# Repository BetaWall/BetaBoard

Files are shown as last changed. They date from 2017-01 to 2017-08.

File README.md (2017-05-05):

*Chat to the devs on [Telegram](https://t.me/joinchat/AAAAAAxiRIuuax58XAVMrQ).*

BetaBoard

A multiplexed APA102 LED driver board for the BetaWall system.

## Features

- Input runs through a single RJ45 connector via RS-485 protocol.
- Outputs SPI to APA102 LEDs.
- Supports up to 32 strips of 256 LEDs.
- Supports daisychaining of up to 128 BetaBoards to drive a total of over 1 Million LEDs.

## Block Diagram
Block Diagram

AGPLv3

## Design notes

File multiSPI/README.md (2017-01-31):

# multiSPI

Scripts that talk SPI to APA102 LEDs using the multiplexing technology on the BetaBoard hardware. 

These are currently written in Python, however the final project will have the SPI multiplexing handled by hardware and this software will only be used for image proccessing and serial output to the BetaBoard.

These are tested and working on a Raspberry Pi 2 running Ubuntu Server.

## Dependancies

Uses WiringPi for the multiplexing, needs to be run on a linux machine with SPI hardware at `/dev/spidev0.0`. This is hardcoded and can be changed by editing the source.

Otherwise the software just uses your device as a file so no SPI libraries are required.

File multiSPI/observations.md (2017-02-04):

# Observations though Practical Testing

Testing shows that outputting data at the default Pi SPI datarate will support 18x21 at 20fps.

By the nature of the APA102 it is faster to wire in less lines of more LEDs.

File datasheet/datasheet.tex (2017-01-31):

\documentclass[a4paper]{article}

\title{BetaBoard Datasheet \texttt{Preliminary}}
\author{Harry Beadle, George Brown}

\usepackage{graphicx}
\usepackage{float}
\usepackage[margin=1in]{geometry}

\begin{document}

\maketitle

\section*{18 Strip APA102 Multiplexer and Driver over RS485}

\section{Features}
\begin{itemize}
\item Drives up to 18 Strips of 255 LEDs, totaling up to 4590 APA102 devices.
\item Takes input using the RS485 protocol.
\item Supports up to 40A continuous current driving the LEDS, with the ability to support much higher output currents with auxiliary power supplies.
\end{itemize}

\begin{figure}[H]
\centering

\caption{Block Diagram}
\end{figure}

\subsection{Protocols}\label{protocols}

\subsubsection{RS485 Data Packet Format}\label{rs485-data-packet-format}

The RS485 Packet is sent from the compute platform to the BetaBoard. It
contains the address of the board, the strip for which the LED data is
for and the LED data.

\begin{center}
\begin{verbatim}
ID[8] STRIP[8] DATA_LENGTH[8] LED1[24] LED2[24] ... LEDN[24]
\end{verbatim}

\begin{table}[H]
\begin{tabular}{lll}
Tag & Bits & Description \\
\hline
\texttt{ID} & 8 & Board ID  \\
\texttt{STRIP} & 8 & Strip Address  \\
\texttt{DATA-LENGTH} & 8 & Number of LEDs to be set from packet \\
\texttt{LED}$n$ & 24 & Three bytes for each color of each LED, in the format \texttt{BGR}
\end{tabular}
\end{table}
\end{center}

As an example setting 1 LED in strip \texttt{0x00} on board ID \texttt{0x00} to \texttt{0xFFFFFF}:

\begin{verbatim}
ID------- STRIP---- DATA_LEN- LED1-------------------------
0000 0000 0000 0000 0000 0001 1111 1111 1111 1111 1111 1111
\end{verbatim}

\end{document}

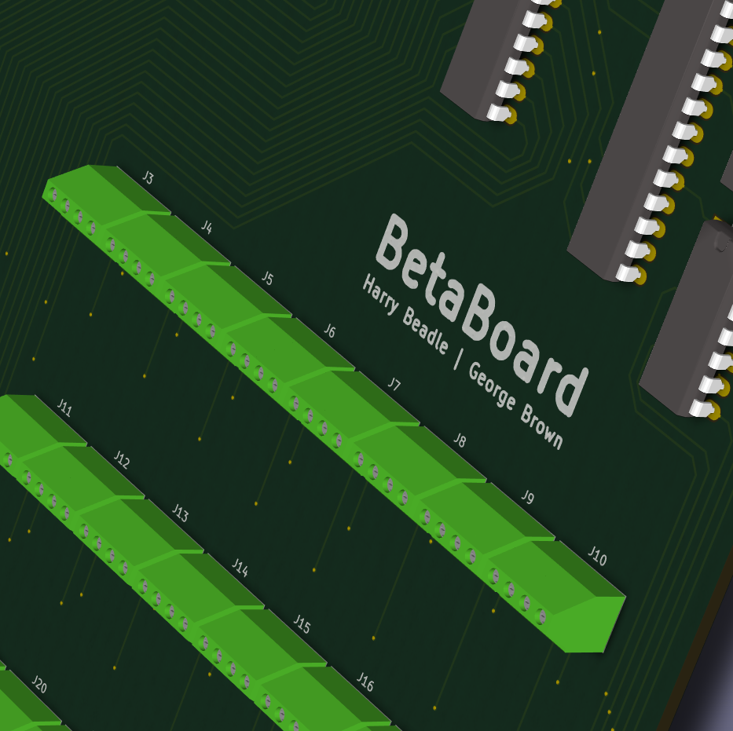
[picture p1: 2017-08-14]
KiCad/3d-render.png

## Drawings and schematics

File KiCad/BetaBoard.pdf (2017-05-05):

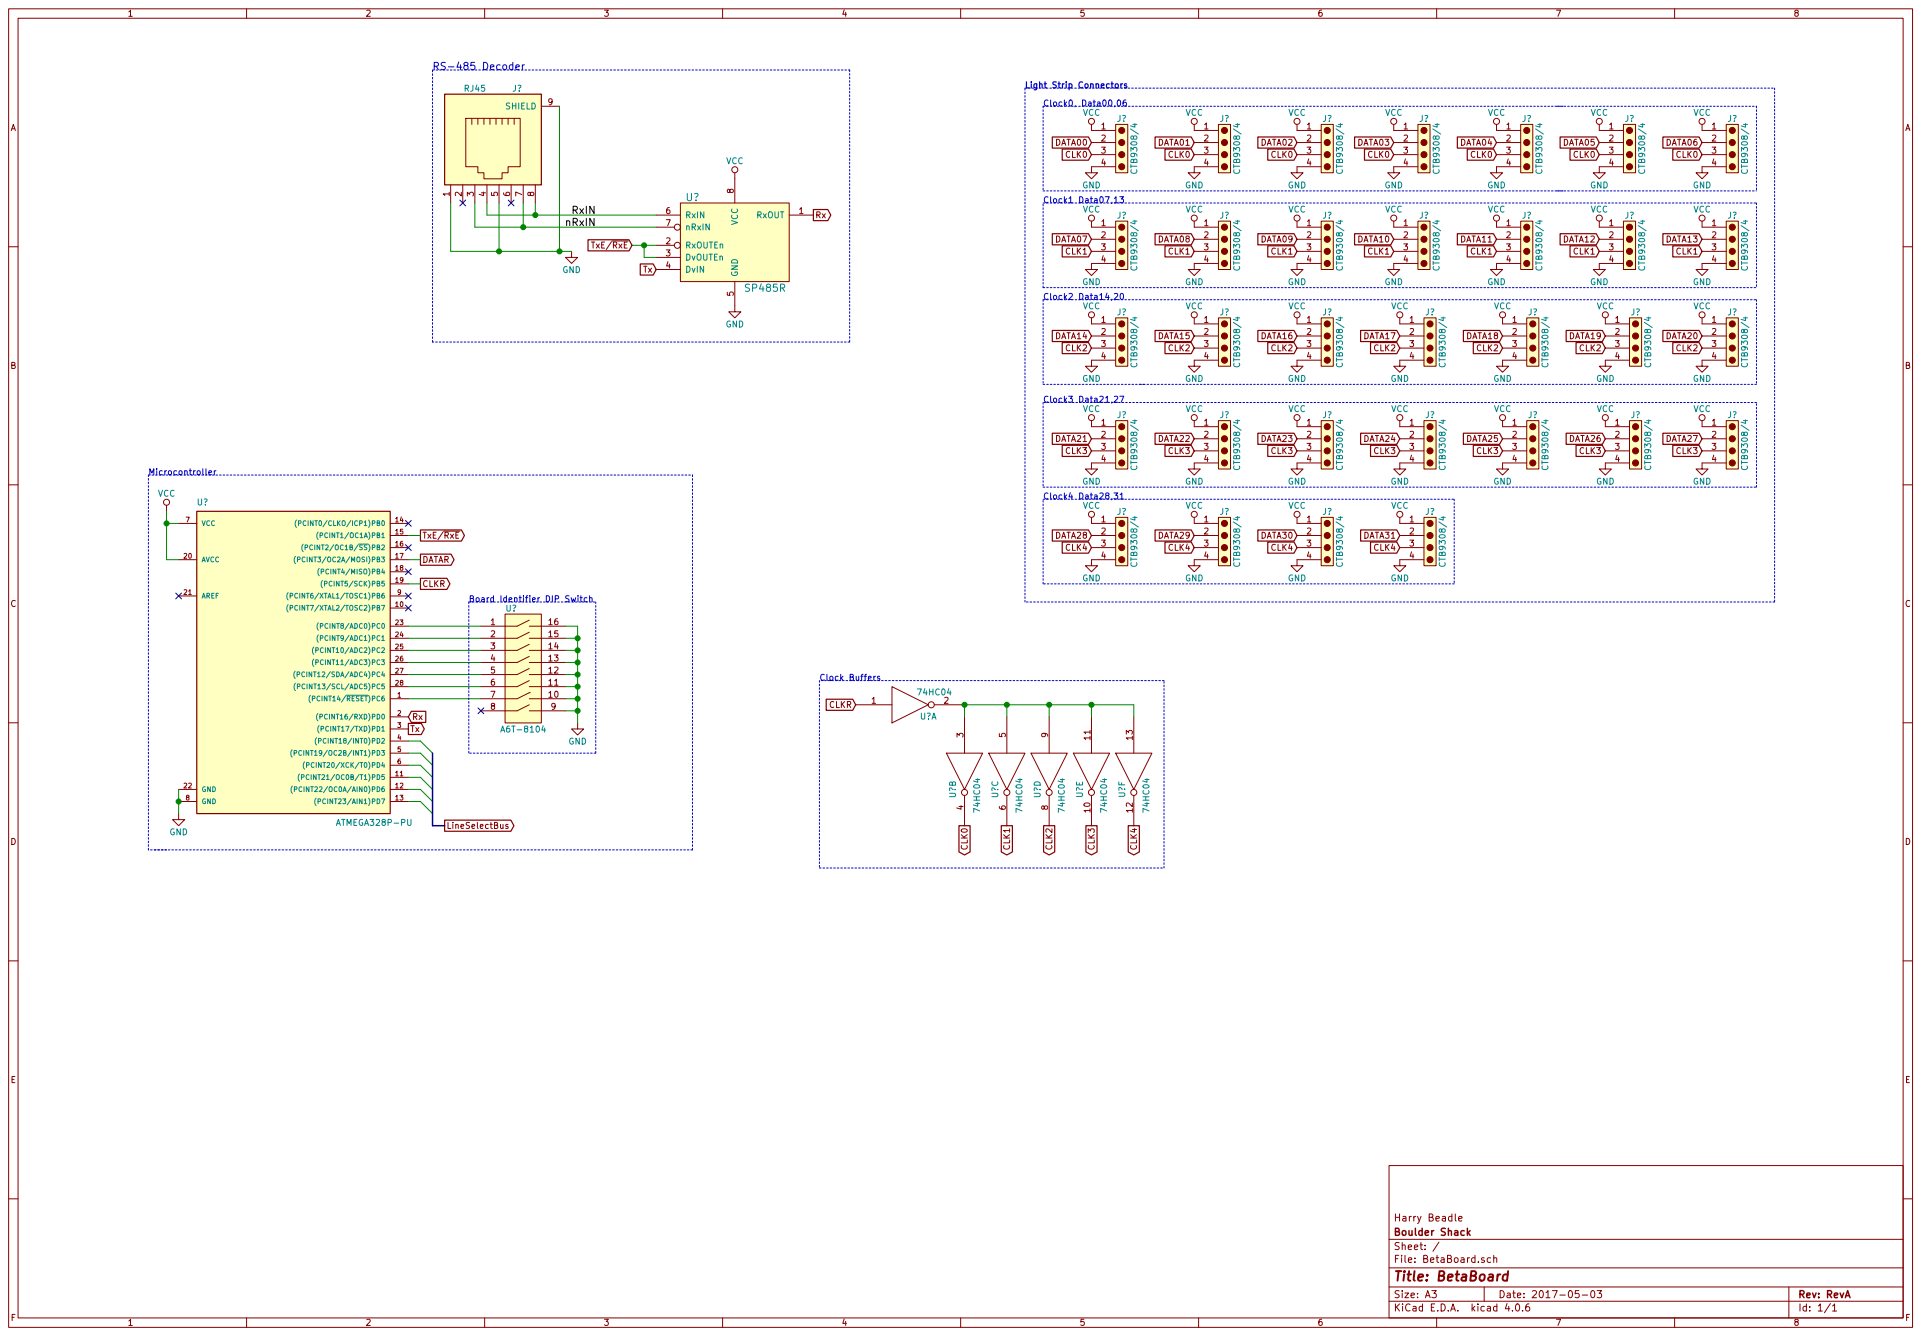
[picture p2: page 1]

VCC GND
Tx TxE/RxE Rx Tx TxE/RxE CLKR

File: BetaBoard.sch Sheet: / Boulder Shack Harry Beadle

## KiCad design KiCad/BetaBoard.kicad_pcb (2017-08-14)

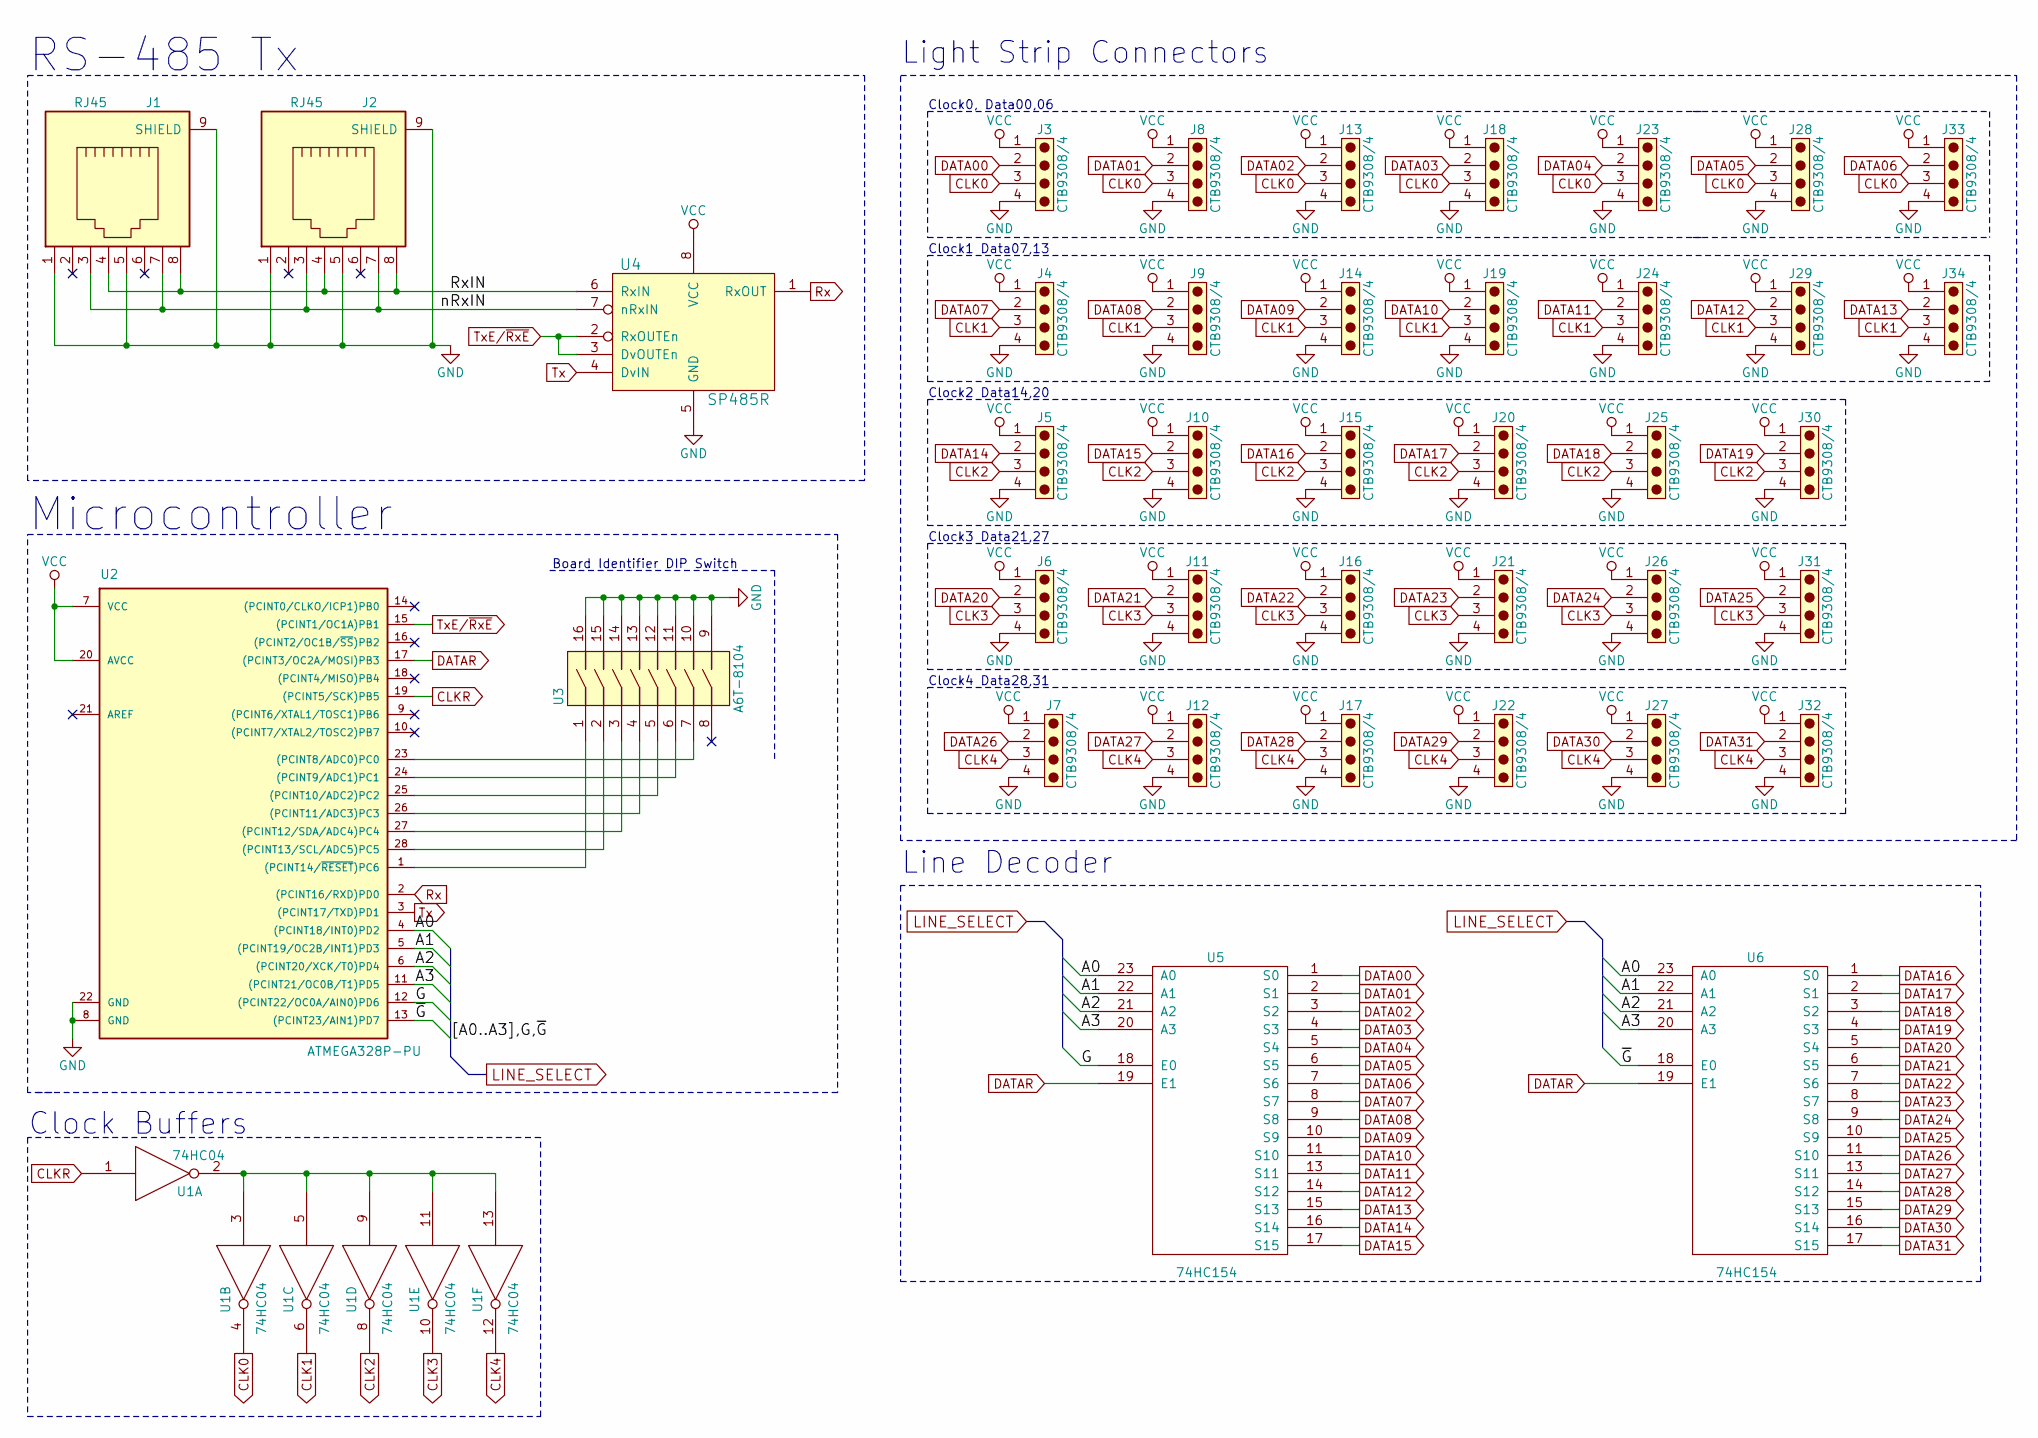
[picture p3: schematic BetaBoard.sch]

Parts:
J1, J2: RJ45; RJ45_TRANSFO_ver2
J3, J4, J5, J6, J7, J8, J9, J10, J11, J12, J13, J14, J15, J16, J17, J18, J19, J20, J21, J22, J23, J24, J25, J26, J27, J28, J29, J30, J31, J32, J33, J34: CTB9308/4; TerminalBlock_Pheonix_MPT-2.54mm_4pol
U1: 74HC04; DIP-14_W7.62mm_Socket_LongPads
U2: ATMEGA328P-PU; DIP-28_W7.62mm_Socket_LongPads
U3: A6T-8104; DIP-16_W7.62mm_Socket_LongPads
U4: SP485R; DIP-8_W7.62mm_Socket_LongPads
U5, U6: 74HC154; DIP-24_W7.62mm_Socket_LongPads

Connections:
/A0: U2.4 ((PCINT18/INT0)PD2), U5.23 (A0), U6.23 (A0)
/A1: U2.5 ((PCINT19/OC2B/INT1)PD3), U5.22 (A1), U6.22 (A1)
/A2: U2.6 ((PCINT20/XCK/T0)PD4), U5.21 (A2), U6.21 (A2)
/A3: U2.11 ((PCINT21/OC0B/T1)PD5), U5.20 (A3), U6.20 (A3)
/G: U2.12 ((PCINT22/OC0A/AIN0)PD6), U5.18 (E0)
/RxIN: J1.4, J1.8, J2.4, J2.8, U4.6 (RxIN)
/nRxIN: J1.3, J1.7, J2.3, J2.7, U4.7 (nRxIN)
/~G: U2.13 ((PCINT23/AIN1)PD7), U6.18 (E0)
CLK0: J3.3, J8.3, J13.3, J18.3, J23.3, J28.3, J33.3, U1.4
CLK1: J4.3, J9.3, J14.3, J19.3, J24.3, J29.3, J34.3, U1.6
CLK2: J5.3, J10.3, J15.3, J20.3, J25.3, J30.3, U1.8
CLK3: J6.3, J11.3, J16.3, J21.3, J26.3, J31.3, U1.10
CLK4: J7.3, J12.3, J17.3, J22.3, J27.3, J32.3, U1.12
CLKR: U1.1, U2.19 ((PCINT5/SCK)PB5)
DATA00: J3.2, U5.1 (S0)
DATA01: J8.2, U5.2 (S1)
DATA02: J13.2, U5.3 (S2)
DATA03: J18.2, U5.4 (S3)
DATA04: J23.2, U5.5 (S4)
DATA05: J28.2, U5.6 (S5)
DATA06: J33.2, U5.7 (S6)
DATA07: J4.2, U5.8 (S7)
DATA08: J9.2, U5.9 (S8)
DATA09: J14.2, U5.10 (S9)
DATA10: J19.2, U5.11 (S10)
DATA11: J24.2, U5.13 (S11)
DATA12: J29.2, U5.14 (S12)
DATA13: J34.2, U5.15 (S13)
DATA14: J5.2, U5.16 (S14)
DATA15: J10.2, U5.17 (S15)
DATA16: J15.2, U6.1 (S0)
DATA17: J20.2, U6.2 (S1)
DATA18: J25.2, U6.3 (S2)
DATA19: J30.2, U6.4 (S3)
DATA20: J6.2, U6.5 (S4)
DATA21: J11.2, U6.6 (S5)
DATA22: J16.2, U6.7 (S6)
DATA23: J21.2, U6.8 (S7)
DATA24: J26.2, U6.9 (S8)
DATA25: J31.2, U6.10 (S9)
DATA26: J7.2, U6.11 (S10)
DATA27: J12.2, U6.13 (S11)
DATA28: J17.2, U6.14 (S12)
DATA29: J22.2, U6.15 (S13)
DATA30: J27.2, U6.16 (S14)
DATA31: J32.2, U6.17 (S15)
DATAR: U2.17 ((PCINT3/OC2A/MOSI)PB3), U5.19 (E1), U6.19 (E1)
GND: J1.1, J1.5, J1.9 (SHIELD), J2.1, J2.5, J2.9 (SHIELD), J3.4, J4.4, J5.4, J6.4, J7.4, J8.4, J9.4, J10.4, J11.4, J12.4, J13.4, J14.4, J15.4, J16.4, J17.4, J18.4, J19.4, J20.4, J21.4, J22.4, J23.4, J24.4, J25.4, J26.4, J27.4, J28.4, J29.4, J30.4, J31.4, J32.4, J33.4, J34.4, U1.7 (GND), U2.8 (GND), U2.22 (GND), U3.9, U3.10, U3.11, U3.12, U3.13, U3.14, U3.15, U3.16, U4.5 (GND), U5.12 (GND), U6.12 (GND)
unnamed: U1.2, U1.3, U1.5, U1.9, U1.11, U1.13
unnamed: U2.1 ((PCINT14/~RESET~)PC6), U3.1
unnamed: U2.23 ((PCINT8/ADC0)PC0), U3.7
unnamed: U2.24 ((PCINT9/ADC1)PC1), U3.6
unnamed: U2.25 ((PCINT10/ADC2)PC2), U3.5
unnamed: U2.26 ((PCINT11/ADC3)PC3), U3.4
unnamed: U2.27 ((PCINT12/SDA/ADC4)PC4), U3.3
unnamed: U2.28 ((PCINT13/SCL/ADC5)PC5), U3.2
Rx: U2.2 ((PCINT16/RXD)PD0), U4.1 (RxOUT)
Tx: U2.3 ((PCINT17/TXD)PD1), U4.4 (DvIN)
TxE/~RxE: U2.15 ((PCINT1/OC1A)PB1), U4.2 (RxOUTEn), U4.3 (DvOUTEn)
VCC: J3.1, J4.1, J5.1, J6.1, J7.1, J8.1, J9.1, J10.1, J11.1, J12.1, J13.1, J14.1, J15.1, J16.1, J17.1, J18.1, J19.1, J20.1, J21.1, J22.1, J23.1, J24.1, J25.1, J26.1, J27.1, J28.1, J29.1, J30.1, J31.1, J32.1, J33.1, J34.1, U1.14 (VCC), U2.7 (VCC), U2.20 (AVCC), U4.8 (VCC), U5.24 (VCC)

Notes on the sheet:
RS-485 Tx
Board Identifier DIP Switch
Microcontroller
Clock0, Data00,06
Clock1 Data07,13
Clock2 Data14,20
Clock3 Data21,27
Clock4 Data28,31
Clock Buffers
Light Strip Connectors
Line Decoder

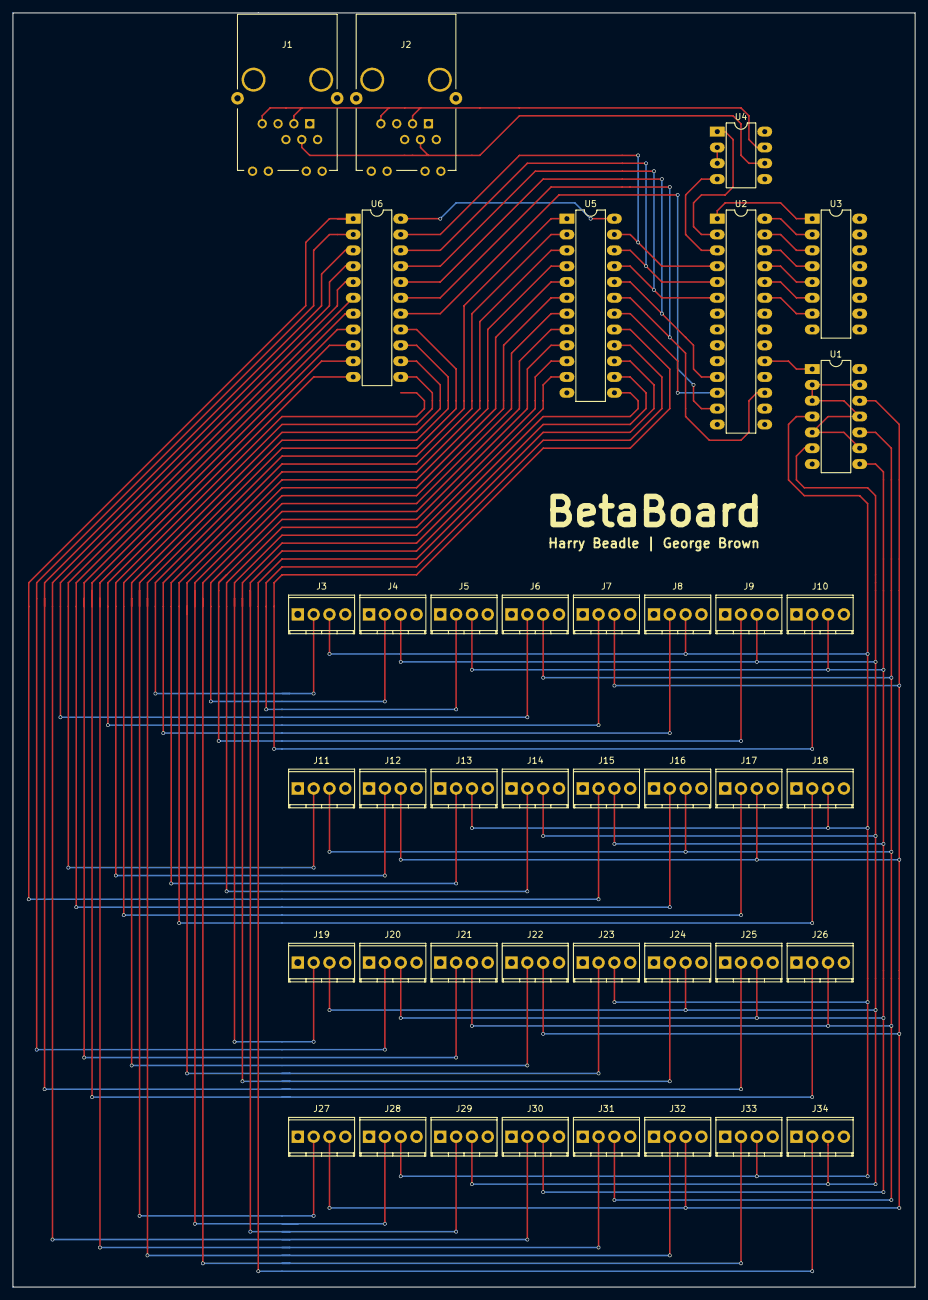
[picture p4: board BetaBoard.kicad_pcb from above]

Board: 2 copper layers, 144.8 x 204.5 mm, 40 parts (0 on the bottom side), 60 nets.

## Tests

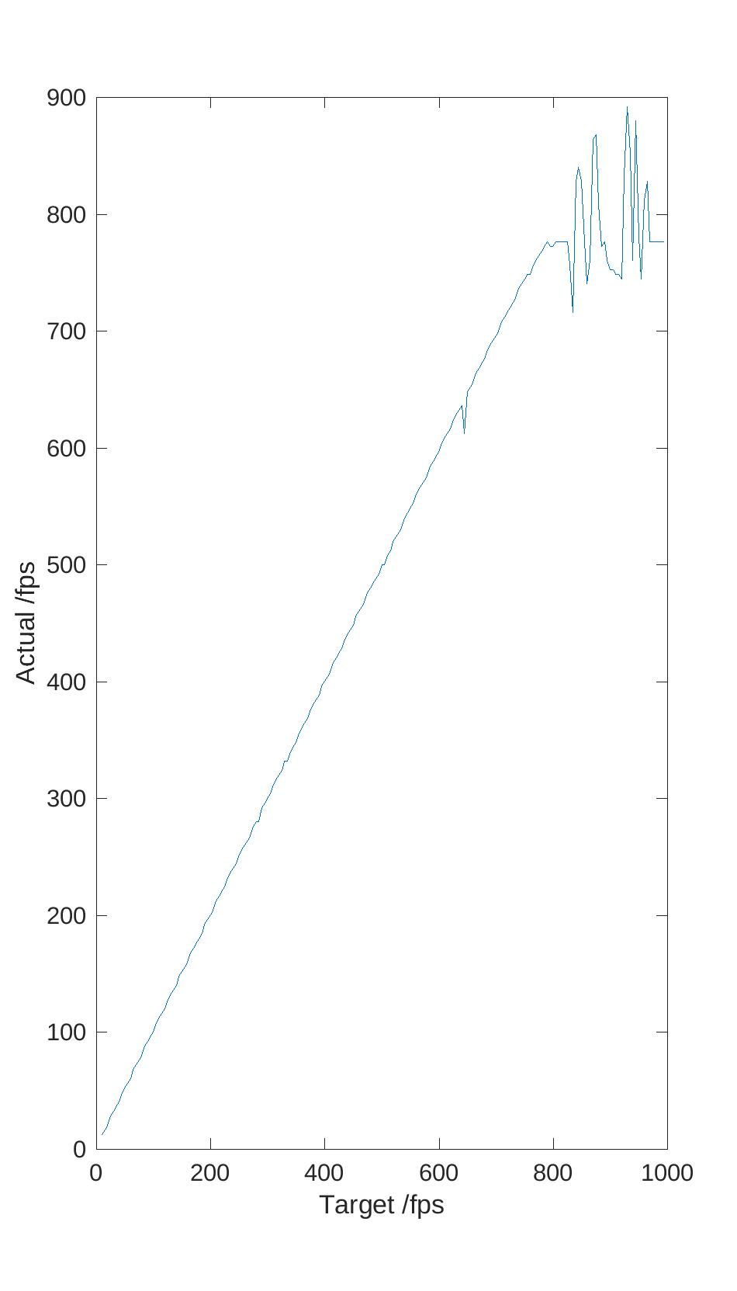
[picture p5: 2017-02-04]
multiSPI/test-suite/frametest.jpg

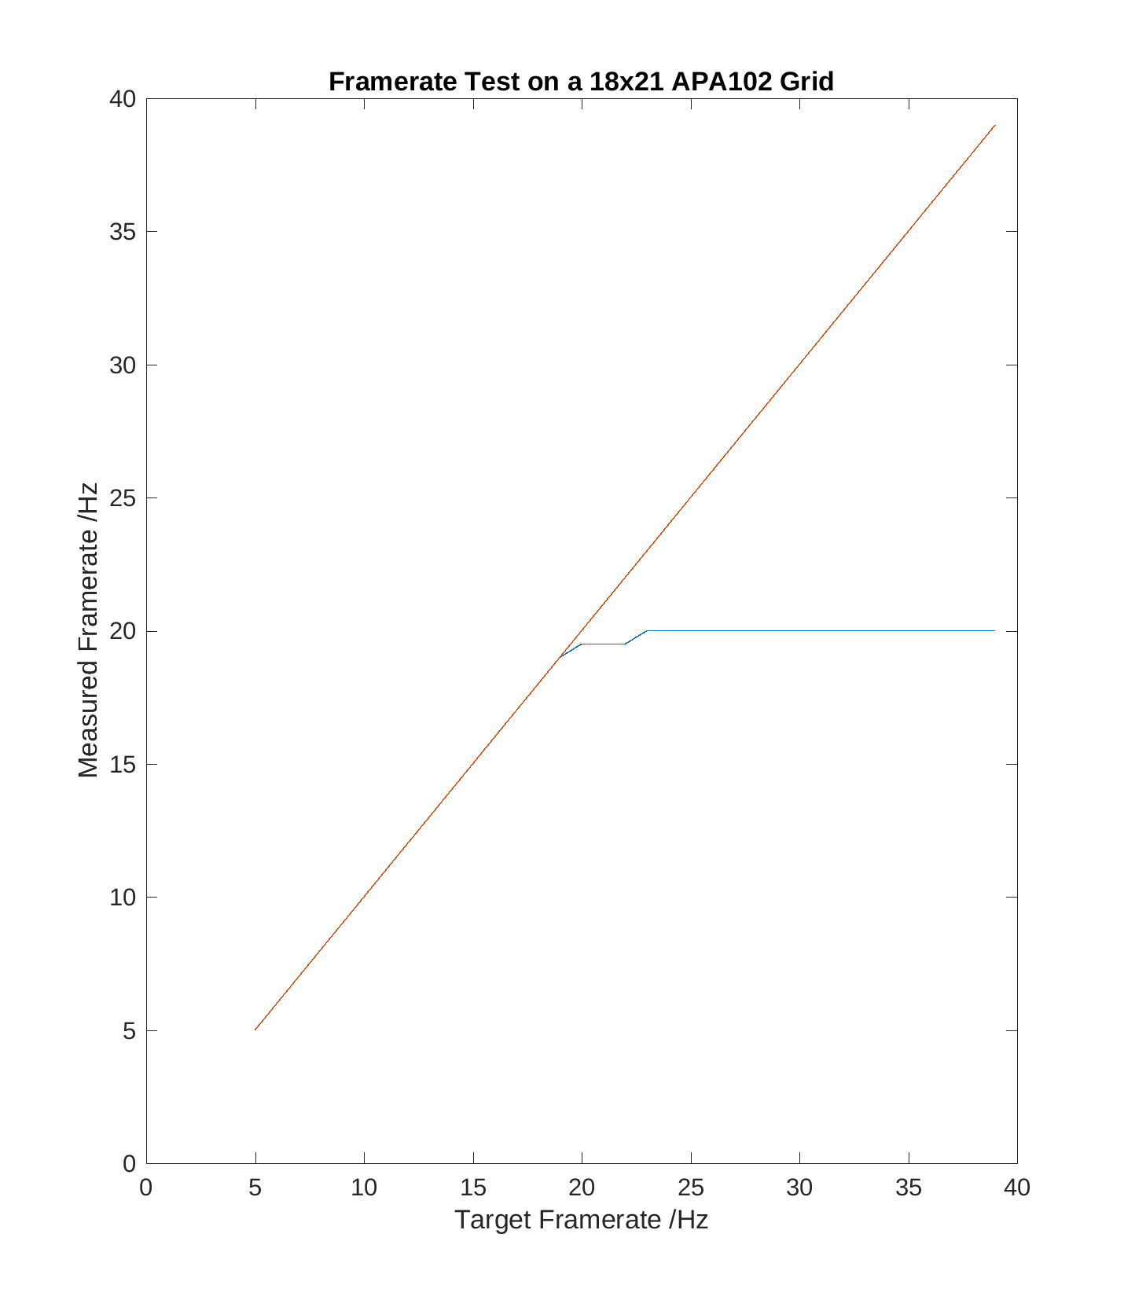
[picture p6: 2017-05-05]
multiSPI/test-suite/frametest.png

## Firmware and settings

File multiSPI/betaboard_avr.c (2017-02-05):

#include <avr/io.h>
#include <avr/interupt.h>

#define BUFFER_SIZE 32 // Make this as big as you can afford
#define STRIP_OUTPUT PORTB
#define BOARD_ID_INPUT PORTA
#define INTENSITY 0xCC

// 256 Byte Input Buffer
char* buffer[BUFFER_SIZE];
int buffer_in, buffer_out;

void init_buffer(void) 
{
	buffer_in = 0;
	buffer_out = 0;
}

int buffer_add(char c)
{
	buffer[buffer_in] = c;
	buffer_in++;
	if (buffer_in == BUFFER_SIZE - 1) {
		// Return buffer_in to start
		buffer_in = 0;
	}
}

char buffer_pop(void)
{
	while (buffer_out == buffer_in) {
		// Wait for a byte rx
		continue;
	}
	char r = buffer[buffer_out];
	buffer_out++;
	if (buffer_out == BUFFER_SIZE - 1) {
		// Return buffer_out to start
		buffer_out = 0;
	}
	return r;
}

// UART Interupt
ISR(USART_RXC_vect) {
	buffer_add(UDR0)
}

void begin_line(void)
{
	// Send start sequence
	// 0x00000000
	for (int i = 0; i < 3; i++) {
		output_spi(0x00);
	}
}

void end_line(void)
{
	// Send end sequence
	// 0xFFFFFFFF
	for (int i = 0; i < 3; i++) {
		output_spi(0xFF);
	}
}

void output_spi(char c) {
	// Make sure nothing is being sent
	// TODO
	// Send char c
	// TODO
	// Wait untill it's sent
	// TODO
	continue;
}

int main(void)
{
	// Initalise
	init_buffer();
	uint8_t board_id = PORTA;
	uint8_t data_length;
	while (1) {
		board_id = buffer_pop();
		STRIP_OUTPUT = buffer_pop();
		data_length = buffer_pop();
		if (board_id == BOARD_ID_INPUT) {
			// Send start, data , end to selected strip.
			begin_line()
			for (int i = 0; i < data_length/3; i+=3) {
				output_spi(INTENSITY);
				output_spi(buffer_pop()); // B
				output_spi(buffer_pop()); // G
				output_spi(buffer_pop()); // R
			}
			end_line();
		} else {
			// Ignore message content, it's not for this board.
			for (int i = 0; i < data_length; i += 3) {
				buffer_pop();
			}
		}
	}
}

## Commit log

2017-01-31 + Early code for testing the LED arrays. Driven by Raspberry pi SPI peripheral.
2017-02-03 add framerate graph
2017-05-05 Started Schematic Entry
    Input Communications
    RJ45 Connector
    RS-485 Decoder
    Controller
    Microcontroller
    DIP Switch for Board ID
    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
    [BetaBoard.kicad_pcb, BetaBoard.sch]
2017-05-05 Added PDF plot of Schematic
2017-07-14 +Add per channel decoder. *Spread out the clock drivers more evenly. *Misc tidy up.
    [BetaBoard.sch]
2017-08-14 + Layout
    [BetaBoard.kicad_pcb, BetaBoard.sch]
2017-08-14 +Silkscreen/EdgeCuts *DRM Fails
    [BetaBoard.kicad_pcb]
